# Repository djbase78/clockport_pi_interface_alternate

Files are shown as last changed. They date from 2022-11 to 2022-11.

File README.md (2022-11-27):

# Alternative PCB for Niklas Ekström's "clockport pi interface"

This is a fork from Niklas Ekström where an alternate PCB layout has been made to enable an even smaller and more low-profile end product.
The fork contains PCB files in KiCAD 6.99 format, and an updated pin constraint file (.ucf) to accomodate for the new PCB.

|  |  |
|---|---|
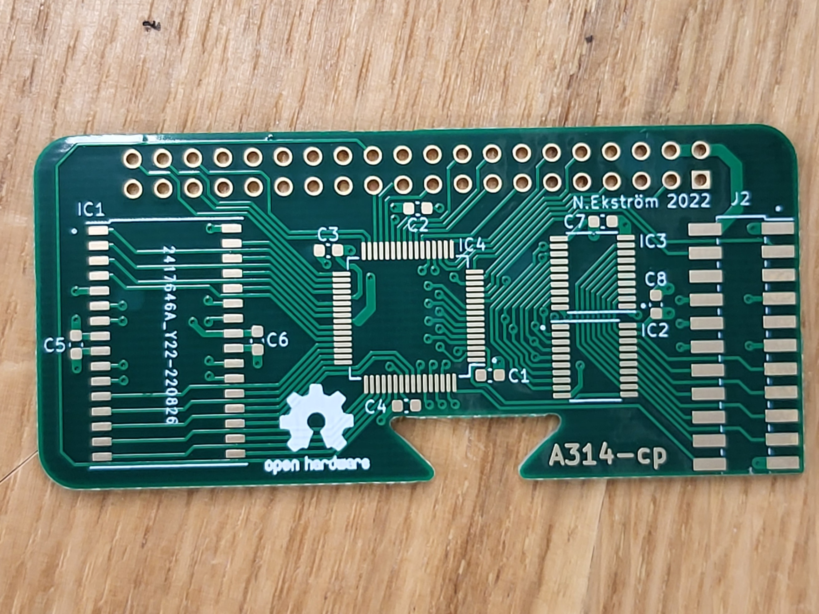
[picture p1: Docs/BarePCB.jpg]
PCB
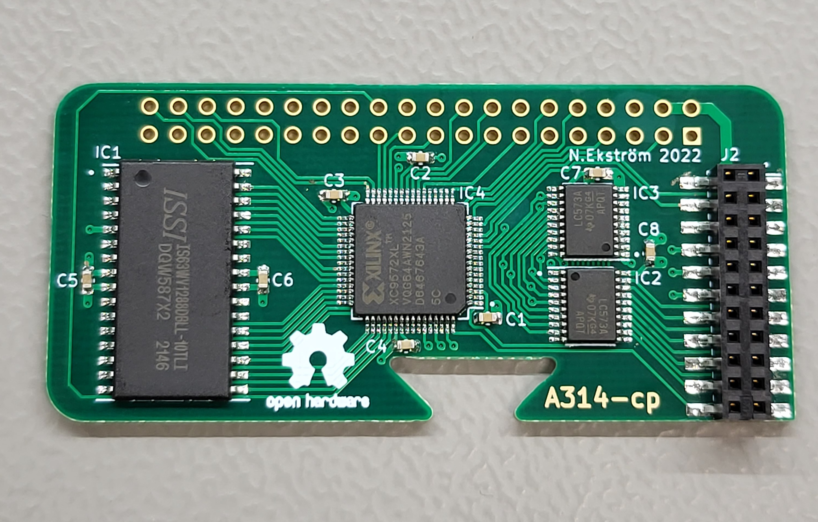
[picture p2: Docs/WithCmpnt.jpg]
PCB /w components
|  |  |
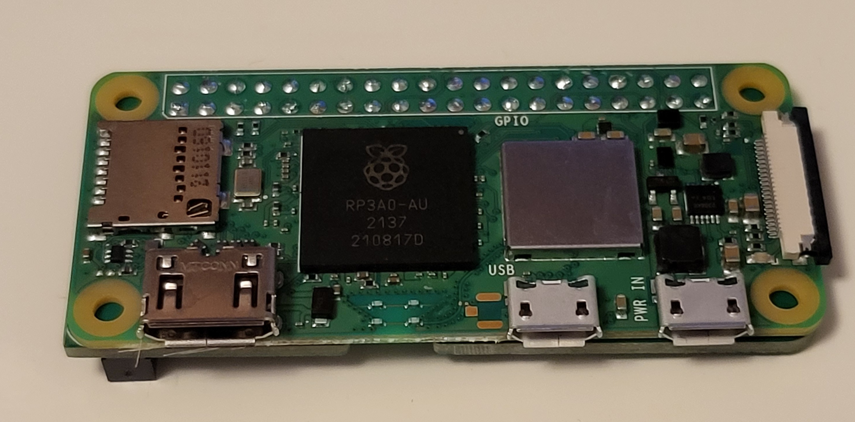
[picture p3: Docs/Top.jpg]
Mounted with RPi Zero 2W
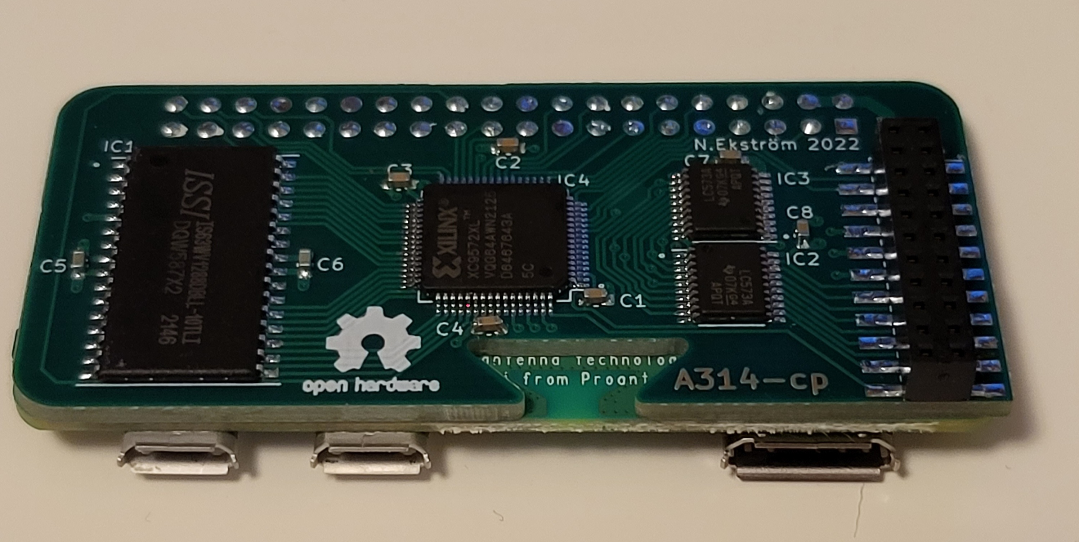
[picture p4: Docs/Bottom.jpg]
Bottom side
|   |  |
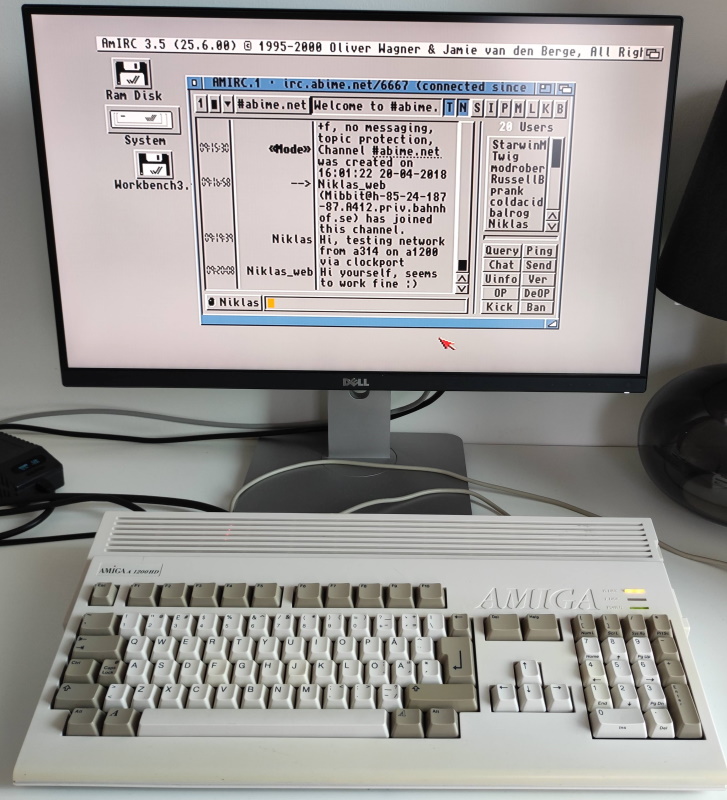
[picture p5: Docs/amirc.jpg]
Running terminal in AmigaOS
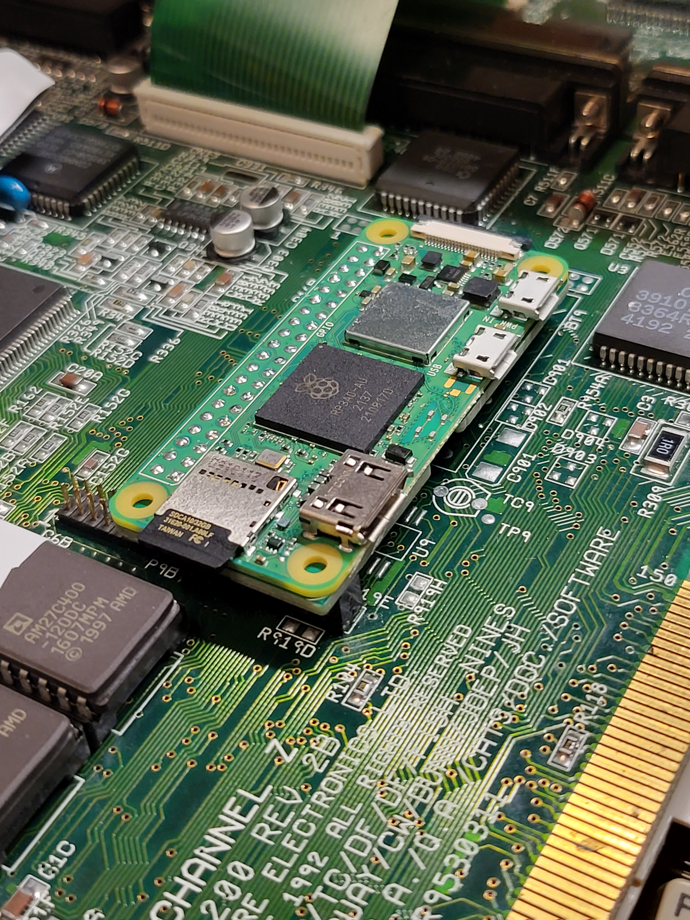
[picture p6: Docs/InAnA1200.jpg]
Low profile installation
|  |  |

## Details about how the interface works

For further details about this excellent project, please visit this forks origin site @ [niklasekstrom/clockport_pi_interface](https://github.com/niklasekstrom/clockport_pi_interface)
You will find a schematic PDF for this forked PCB in the Hardware folder.

## Bill of materials

| References | Value | Footprint | Quantity |
|---|---|---|---|
| C1, C2, C3, C4, C5, C6, C7, C8 | 0.1u | C_0603_1608Metric | 8 |
| U1 | XC9572XL-VQ64 | TQFP-64_10x10mm_P0.5mm | 1 |
| IC2, IC3 | SN74LVC573APWRE4<br>(alt: 74LVC573APW,118) | SOP65P640X120-20N | 2 |
| IC1 | IS63WV1288DBLL-10TLI<br>(alt: IS61WV1288EEBLL-10TLI) | SOIC127P1176X120-32N | 1 |
| J1 | Raspberry Pi Zero 2W | PinSocket_2x20_P2.54mm_Vertical | 1 |
| J2 | Molex 87381-2218<br>2row, 11pos, 2mm grid | PinSocket_2x11_P2.00mm_Vertical | 1 |

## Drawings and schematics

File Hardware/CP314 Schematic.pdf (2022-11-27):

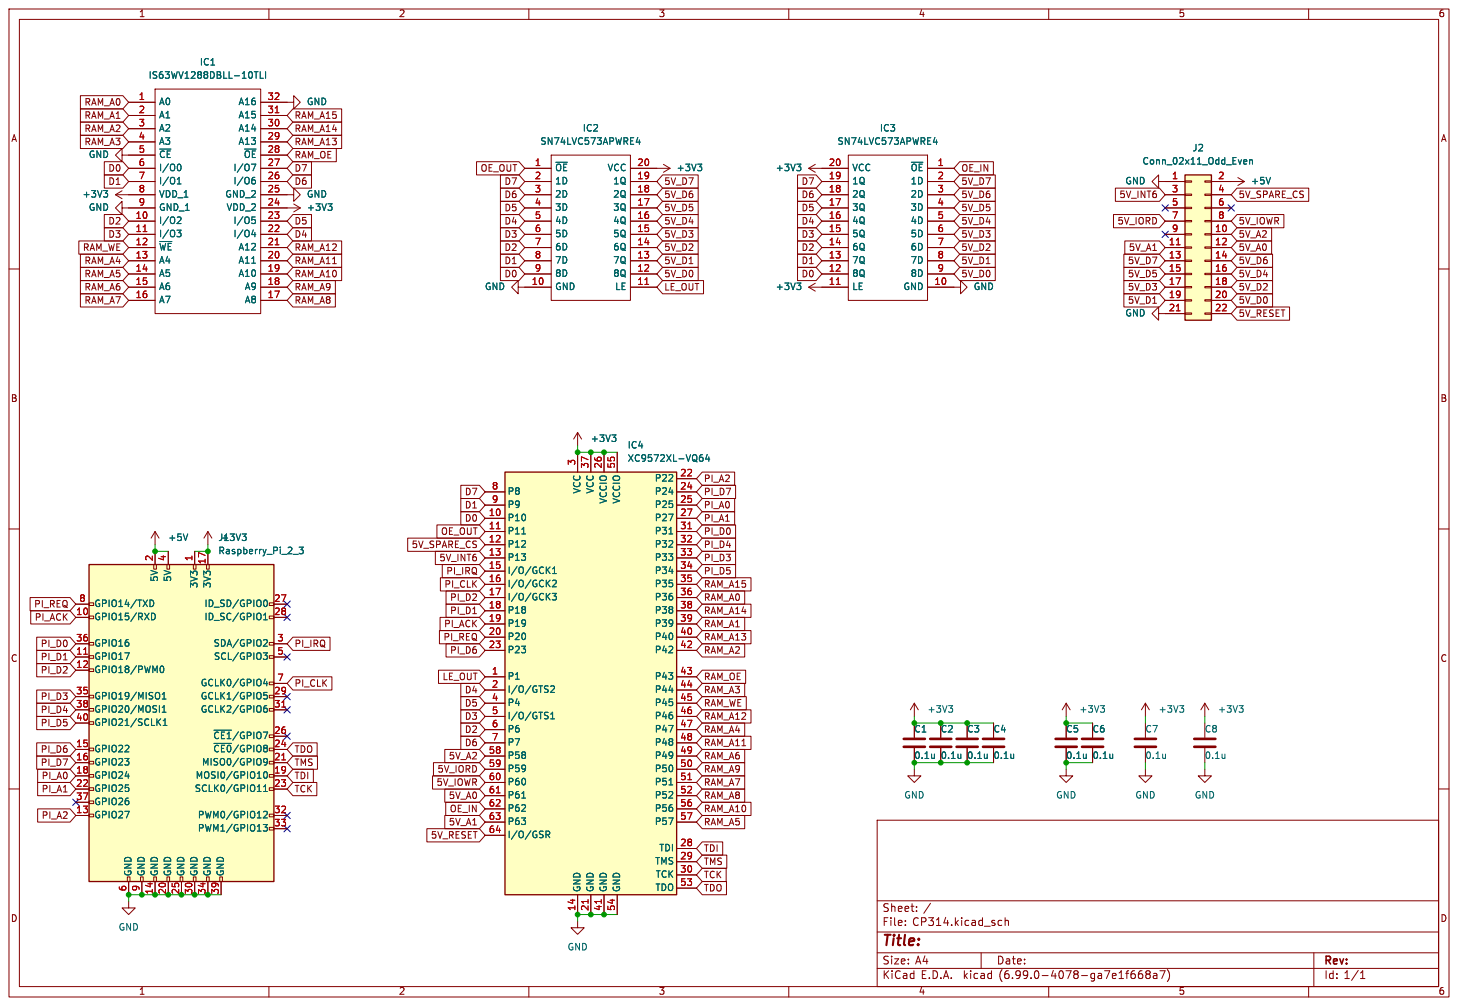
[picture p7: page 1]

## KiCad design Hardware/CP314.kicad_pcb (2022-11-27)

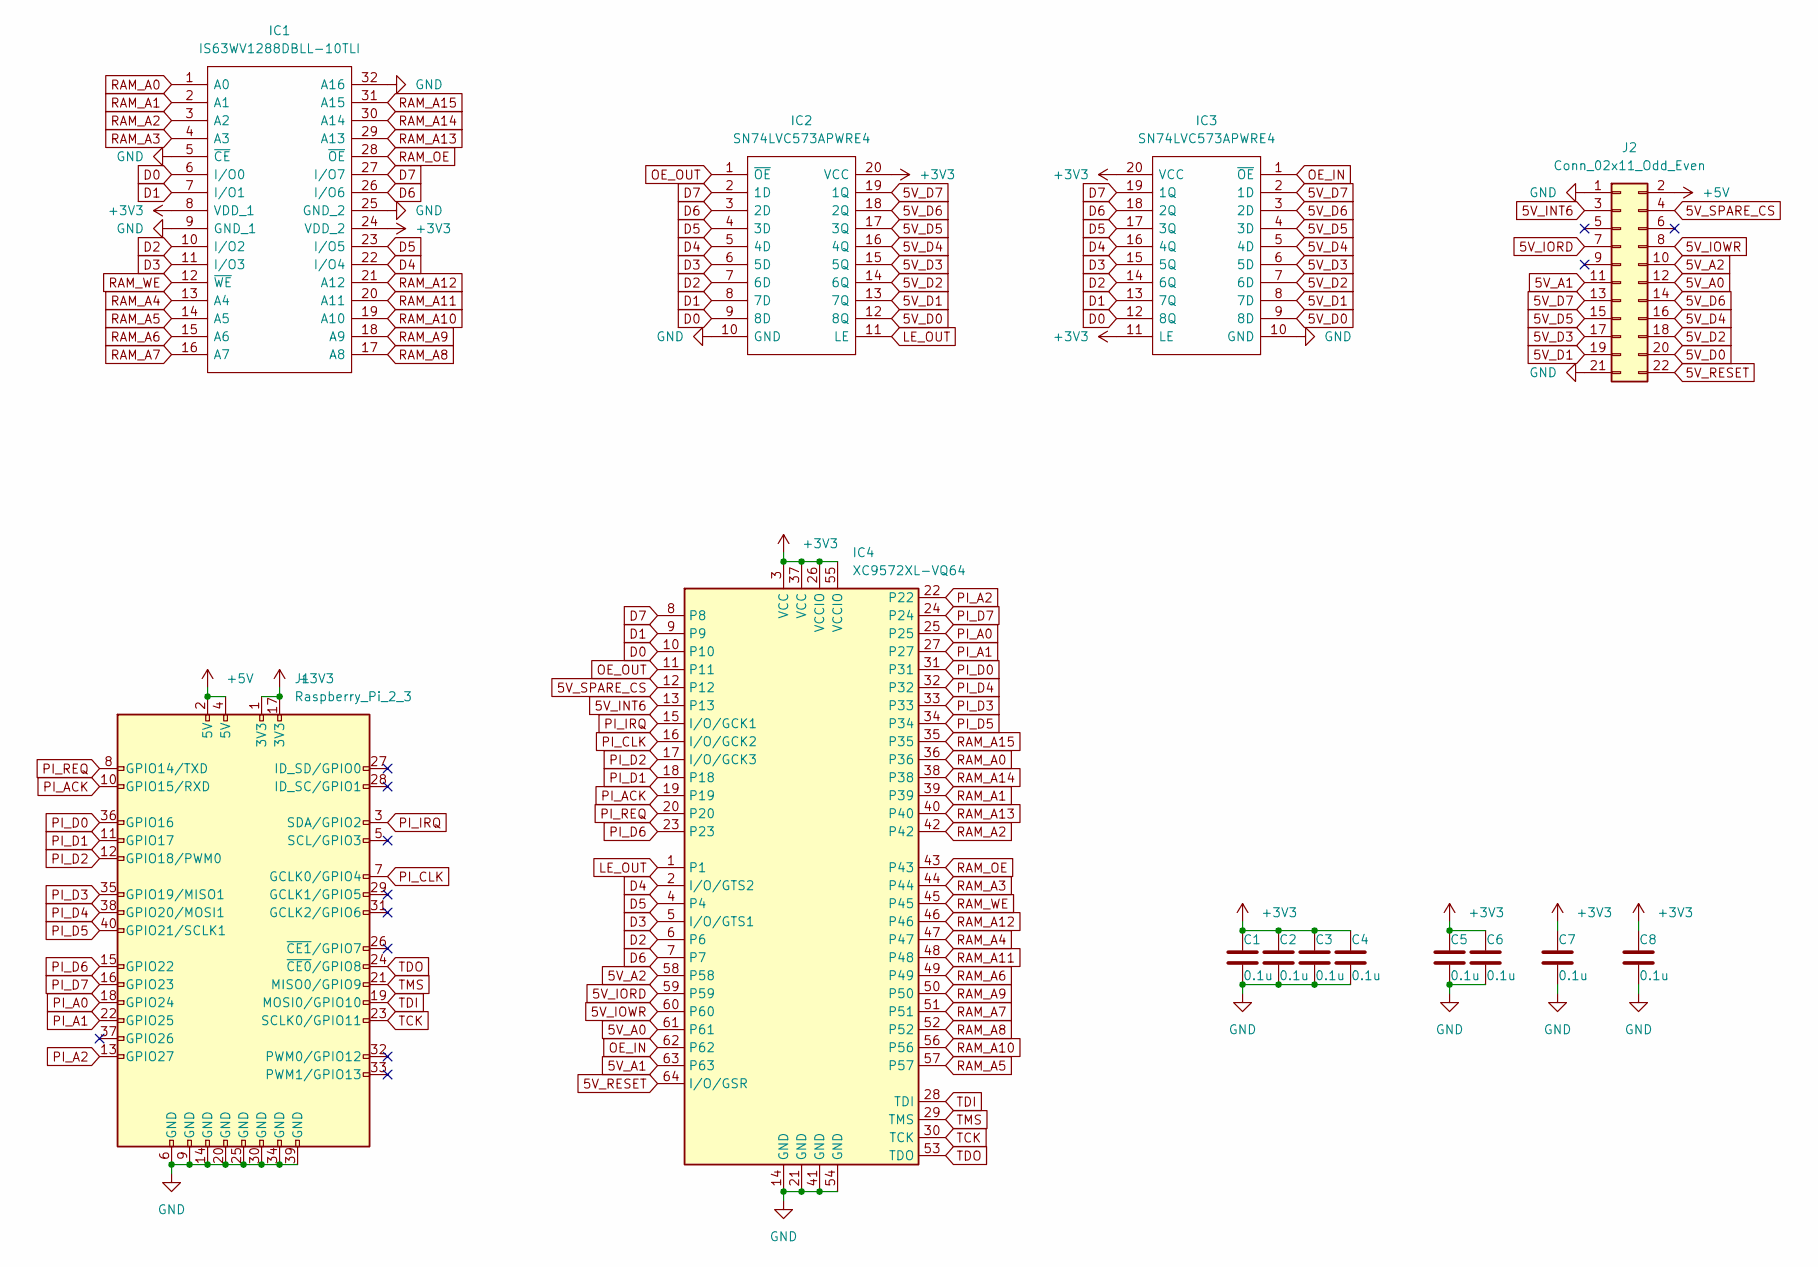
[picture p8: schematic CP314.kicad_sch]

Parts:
C1, C2, C3, C4, C5, C6, C7, C8: 0.1u; C_0603_1608Metric
IC1: IS63WV1288DBLL-10TLI; TSOP-II-32_21.0x10.2mm_P1.27mm; Mouser Part Number 870-63WV1288DB10TLI
IC2, IC3: SN74LVC573APWRE4; TSSOP-20_4.4x6.5mm_P0.65mm; Mouser Part Number 595-SN74LVC573APWRE4
IC4: XC9572XL-VQ64; TQFP-64_10x10mm_P0.5mm
J1: Raspberry_Pi_2_3; ADA3708_RPI-ZERO_NO_HOLES
J2: Conn_02x11_Odd_Even; PinSocket_2x11_P2.00mm_Vertical_SMD

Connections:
5V_A0: IC4.61, J2.12
5V_A1: IC4.63, J2.11
5V_A2: IC4.58, J2.10
5V_D0: IC2.12 (8Q), IC3.9 (8D), J2.20
5V_D1: IC2.13 (7Q), IC3.8 (7D), J2.19
5V_D2: IC2.14 (6Q), IC3.7 (6D), J2.18
5V_D3: IC2.15 (5Q), IC3.6 (5D), J2.17
5V_D4: IC2.16 (4Q), IC3.5 (4D), J2.16
5V_D5: IC2.17 (3Q), IC3.4 (3D), J2.15
5V_D6: IC2.18 (2Q), IC3.3 (2D), J2.14
5V_D7: IC2.19 (1Q), IC3.2 (1D), J2.13
5V_INT6: IC4.13, J2.3
5V_IORD: IC4.59, J2.7
5V_IOWR: IC4.60, J2.8
5V_RESET: IC4.64 (I/O/GSR), J2.22
5V_SPARE_CS: IC4.12, J2.4
+3V3: C1.1, C2.1, C3.1, C4.1, C5.1, C6.1, C7.1, C8.1, IC1.8 (VDD_1), IC1.24 (VDD_2), IC2.20 (VCC), IC3.11 (LE), IC3.20 (VCC), IC4.3 (VCC), IC4.26 (VCCIO), IC4.37 (VCC), IC4.55 (VCCIO), J1.1 (3V3), J1.17 (3V3)
+5V: J1.2 (5V), J1.4 (5V), J2.2
D0: IC1.6 (I/O0), IC2.9 (8D), IC3.12 (8Q), IC4.10
D1: IC1.7 (I/O1), IC2.8 (7D), IC3.13 (7Q), IC4.9
D2: IC1.10 (I/O2), IC2.7 (6D), IC3.14 (6Q), IC4.6
D3: IC1.11 (I/O3), IC2.6 (5D), IC3.15 (5Q), IC4.5 (I/O/GTS1)
D4: IC1.22 (I/O4), IC2.5 (4D), IC3.16 (4Q), IC4.2 (I/O/GTS2)
D5: IC1.23 (I/O5), IC2.4 (3D), IC3.17 (3Q), IC4.4
D6: IC1.26 (I/O6), IC2.3 (2D), IC3.18 (2Q), IC4.7
D7: IC1.27 (I/O7), IC2.2 (1D), IC3.19 (1Q), IC4.8
GND: C1.2, C2.2, C3.2, C4.2, C5.2, C6.2, C7.2, C8.2, IC1.5 (~CE), IC1.9 (GND_1), IC1.25 (GND_2), IC1.32 (A16), IC2.10 (GND), IC3.10 (GND), IC4.14 (GND), IC4.21 (GND), IC4.41 (GND), IC4.54 (GND), J1.6 (GND), J1.9 (GND), J1.14 (GND), J1.20 (GND), J1.25 (GND), J1.30 (GND), J1.34 (GND), J1.39 (GND), J2.1, J2.21
LE_OUT: IC2.11 (LE), IC4.1
OE_IN: IC3.1 (~OE), IC4.62
OE_OUT: IC2.1 (~OE), IC4.11
PI_A0: IC4.25, J1.18 (GPIO24)
PI_A1: IC4.27, J1.22 (GPIO25)
PI_A2: IC4.22, J1.13 (GPIO27)
PI_ACK: IC4.19, J1.10 (GPIO15/RXD)
PI_CLK: IC4.16 (I/O/GCK2), J1.7 (GCLK0/GPIO4)
PI_D0: IC4.31, J1.36 (GPIO16)
PI_D1: IC4.18, J1.11 (GPIO17)
PI_D2: IC4.17 (I/O/GCK3), J1.12 (GPIO18/PWM0)
PI_D3: IC4.33, J1.35 (GPIO19/MISO1)
PI_D4: IC4.32, J1.38 (GPIO20/MOSI1)
PI_D5: IC4.34, J1.40 (GPIO21/SCLK1)
PI_D6: IC4.23, J1.15 (GPIO22)
PI_D7: IC4.24, J1.16 (GPIO23)
PI_IRQ: IC4.15 (I/O/GCK1), J1.3 (SDA/GPIO2)
PI_REQ: IC4.20, J1.8 (GPIO14/TXD)
RAM_A0: IC1.1 (A0), IC4.36
RAM_A1: IC1.2 (A1), IC4.39
RAM_A2: IC1.3 (A2), IC4.42
RAM_A3: IC1.4 (A3), IC4.44
RAM_A4: IC1.13 (A4), IC4.47
RAM_A5: IC1.14 (A5), IC4.57
RAM_A6: IC1.15 (A6), IC4.49
RAM_A7: IC1.16 (A7), IC4.51
RAM_A8: IC1.17 (A8), IC4.52
RAM_A9: IC1.18 (A9), IC4.50
RAM_A10: IC1.19 (A10), IC4.56
RAM_A11: IC1.20 (A11), IC4.48
RAM_A12: IC1.21 (A12), IC4.46
RAM_A13: IC1.29 (A13), IC4.40
RAM_A14: IC1.30 (A14), IC4.38
RAM_A15: IC1.31 (A15), IC4.35
RAM_OE: IC1.28 (~OE), IC4.43
RAM_WE: IC1.12 (~WE), IC4.45
TCK: IC4.30 (TCK), J1.23 (SCLK0/GPIO11)
TDI: IC4.28 (TDI), J1.19 (MOSI0/GPIO10)
TDO: IC4.53 (TDO), J1.24 (~CE0/GPIO8)
TMS: IC4.29 (TMS), J1.21 (MISO0/GPIO9)

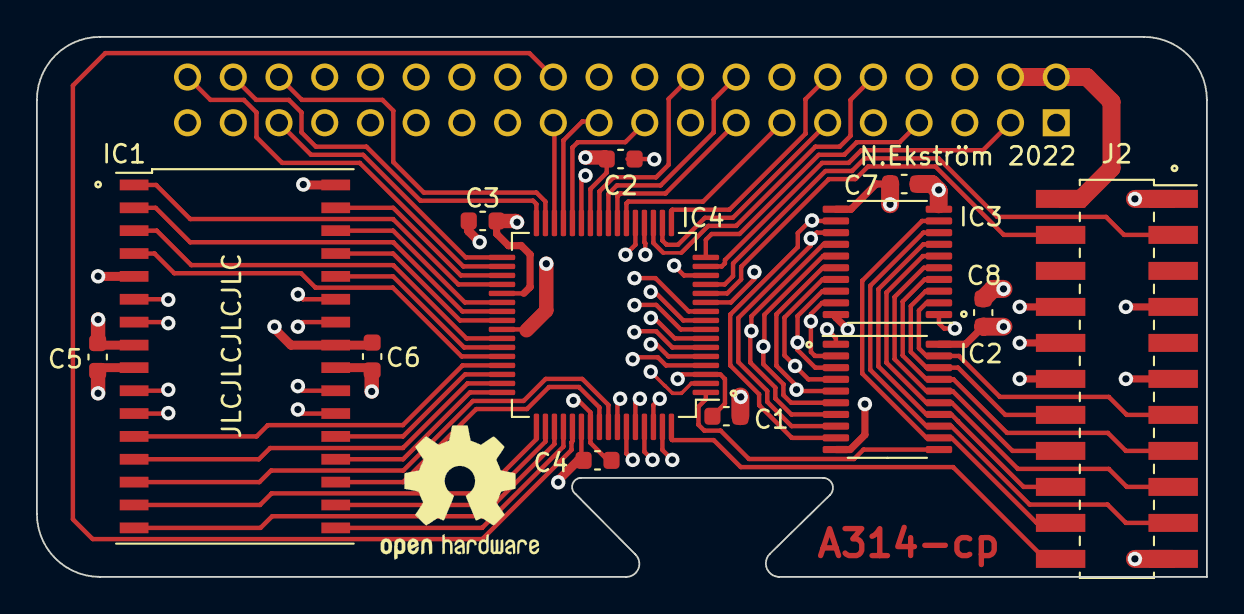
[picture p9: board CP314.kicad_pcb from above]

Board: 4 copper layers, 65.0 x 30.0 mm, 14 parts (1 on the bottom side), 67 nets.

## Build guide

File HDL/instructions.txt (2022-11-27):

Verify that the CPLD is present and found:

./openFPGALoader -c libgpiod --pins 10:8:11:9 --detect

Write the programming file cp_pi_if.jed. For a -10 speed grade CPLD you use:

./openFPGALoader -c libgpiod --pins 10:8:11:9 -f cp_pi_if-10.jed

...and likewise for a -5 speedgrade you use:

./openFPGALoader -c libgpiod --pins 10:8:11:9 -f cp_pi_if-10.jed

There is no jed file prepared for the -7 speed. You may try either of the above, and if they don't work - PM me, and I'll see what I can muster up :)

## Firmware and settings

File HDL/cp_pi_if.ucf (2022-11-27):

#PACE: Start of Constraints generated by PACE

#PACE: Start of PACE I/O Pin Assignments
NET "CLK"  LOC = "P16"  ;
#NET "RESET_n"  LOC = "P64"  ;
NET "RTC_CS_n"  LOC = "P12"  ;
NET "IORD_n"  LOC = "P59"  ;
NET "IOWR_n"  LOC = "P60"  ;
NET "D<0>"  LOC = "P10"  ;
NET "D<1>"  LOC = "P9"  ;
NET "D<2>"  LOC = "P6"  ;
NET "D<3>"  LOC = "P5"  ;
NET "D<4>"  LOC = "P2"  ;
NET "D<5>"  LOC = "P4"  ;
NET "D<6>"  LOC = "P7"  ;
NET "D<7>"  LOC = "P8"  ;
NET "CP_A<0>"  LOC = "P61"  ;
NET "CP_A<1>"  LOC = "P63"  ;
#NET "CP_A<2>"  LOC = "P58"  ;
NET "INT6_n"  LOC = "P13"  ;
NET "LE_OUT"  LOC = "P1"  ;
NET "OE_OUT_n"  LOC = "P11"  ;
NET "OE_IN_n"  LOC = "P62"  ;
NET "PI_REQ"  LOC = "P20"  ;
NET "PI_ACK"  LOC = "P19"  ;
NET "PI_A<0>"  LOC = "P25"  ;
NET "PI_A<1>"  LOC = "P27"  ;
NET "PI_WR"  LOC = "P22"  ;
NET "PI_D<0>"  LOC = "P31"  ;
NET "PI_D<1>"  LOC = "P18"  ;
NET "PI_D<2>"  LOC = "P17"  ;
NET "PI_D<3>"  LOC = "P33"  ;
NET "PI_D<4>"  LOC = "P32"  ;
NET "PI_D<5>"  LOC = "P34"  ;
NET "PI_D<6>"  LOC = "P23"  ;
NET "PI_D<7>"  LOC = "P24"  ;
NET "PI_IRQ"  LOC = "P15"  ;
NET "RAM_A<0>"  LOC = "P36"  ;
NET "RAM_A<1>"  LOC = "P39"  ;
NET "RAM_A<2>"  LOC = "P42"  ;
NET "RAM_A<3>"  LOC = "P44"  ;
NET "RAM_A<4>"  LOC = "P47"  ;
NET "RAM_A<5>"  LOC = "P57"  ;
NET "RAM_A<6>"  LOC = "P49"  ;
NET "RAM_A<7>"  LOC = "P51"  ;
NET "RAM_A<8>"  LOC = "P52"  ;
NET "RAM_A<9>"  LOC = "P50"  ;
NET "RAM_A<10>"  LOC = "P56"  ;
NET "RAM_A<11>"  LOC = "P48"  ;
NET "RAM_A<12>"  LOC = "P46"  ;
NET "RAM_A<13>"  LOC = "P40"  ;
NET "RAM_A<14>"  LOC = "P38"  ;
NET "RAM_A<15>"  LOC = "P35"  ;
NET "RAM_OE_n"  LOC = "P43"  ;
NET "RAM_WE_n"  LOC = "P45"  ;

#PACE: Start of PACE Area Constraints

#PACE: Start of PACE Prohibit Constraints

#PACE: End of Constraints generated by PACE
